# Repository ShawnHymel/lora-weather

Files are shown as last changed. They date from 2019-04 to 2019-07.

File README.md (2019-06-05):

LoRa Weather Station
====================

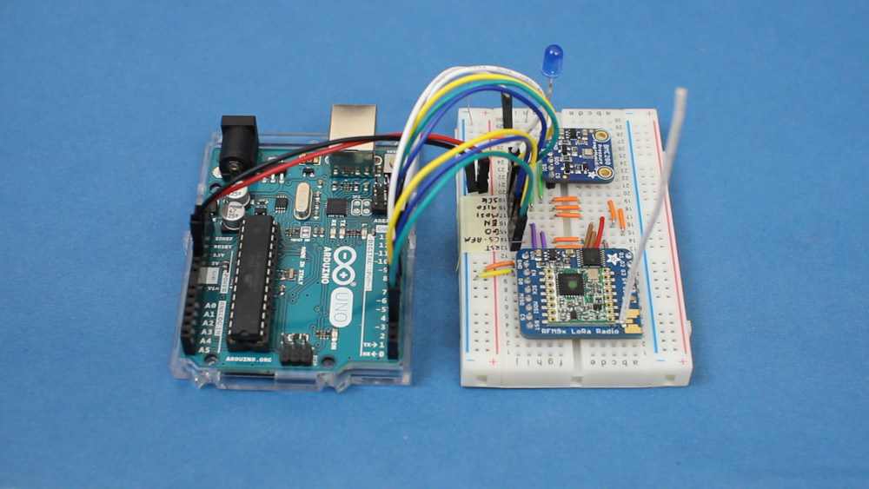
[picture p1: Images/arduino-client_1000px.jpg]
Arduino LoRa and BME280 client


LoRa client and server. Arduino reads temperature, humidity, and pressure data from BME280 sensor and sends it over a simple LoRa wireless connection to a Raspberry Pi.

Required Parts
--------------

 - [Arduino UNO](https://www.digikey.com/product-detail/en/A000066/1050-1024-ND/2784006/)
 - 2x [Adafruit RFM95W LoRa Breakout](https://www.digikey.com/product-detail/en/adafruit-industries-llc/3072/1528-1667-ND/6005357)
 - [Adafruit BME280 Breakout](https://www.digikey.com/product-detail/en/adafruit-industries-llc/2652/1528-1359-ND/5604372)
 - [Raspberry Pi 3 Model B+](https://www.digikey.com/product-detail/en/raspberry-pi/RASPBERRY-PI-3-MODEL-B/1690-1025-ND/8571724)
 - 2x [Breadboards](https://www.digikey.com/product-detail/en/bud-industries/BB-32621/377-2094-ND/4156445)
 - [Jumper wires](https://www.digikey.com/product-detail/en/global-specialties/WK-2/BKWK-2-ND/5231341)

Hardware Setup
--------------

Connect the Arduino as shown:

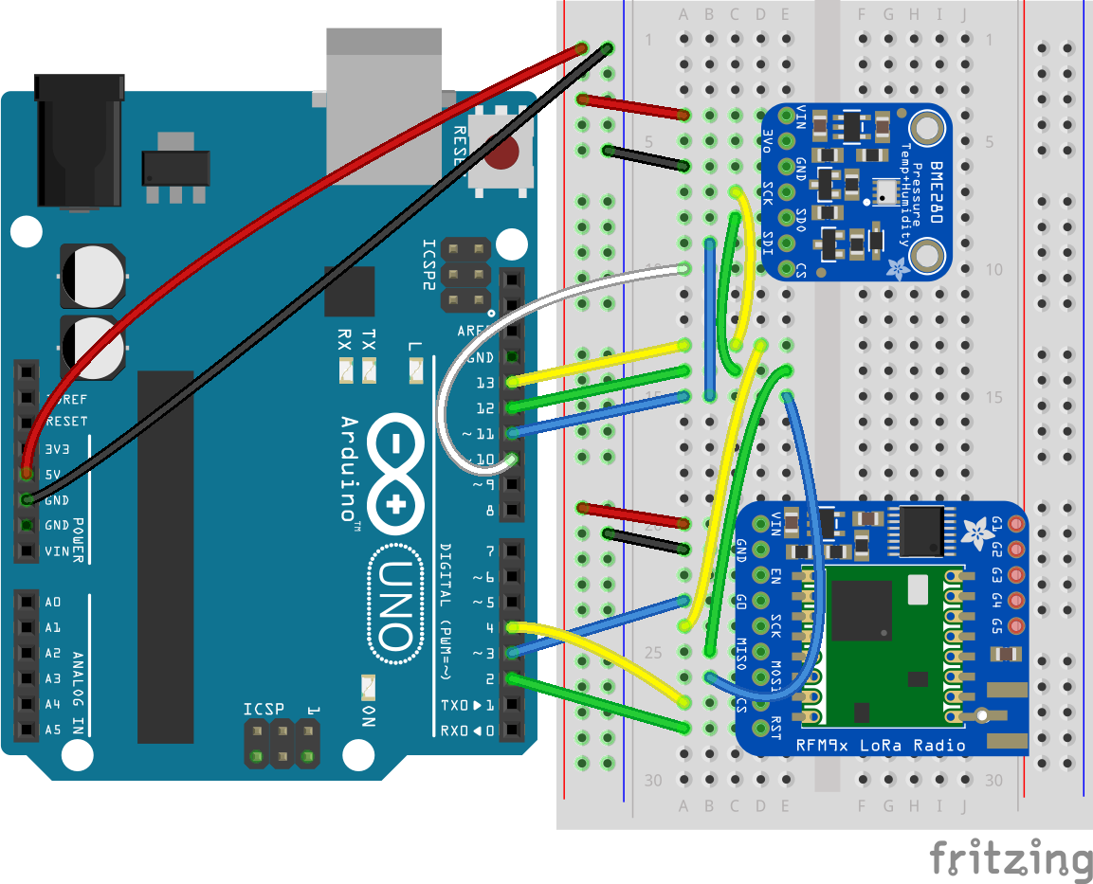
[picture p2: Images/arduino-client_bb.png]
Arduino radio and sensor connections


Connect the Raspberry Pi as shown:

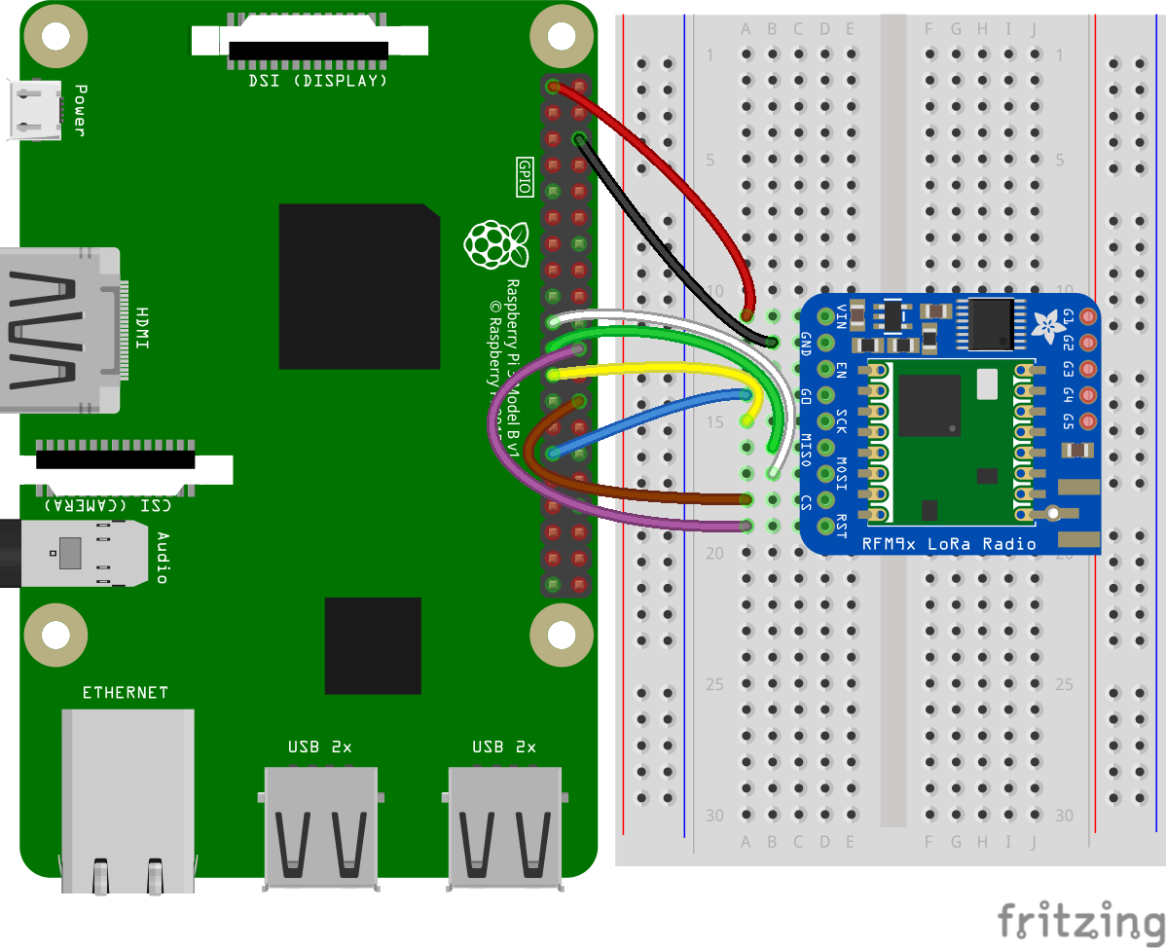
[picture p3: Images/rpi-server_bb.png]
Raspberry Pi radio connections


Server Software
---------------

Install Raspbian (with Desktop) on the Raspberry Pi. From a console, run the following command to install the RFM9x Python package:

```
pip install adafruit-circuitpython-rfm9x
```

Go into the *Python* directory of this repo and run *lora-weather-server.py*.

```
python lora-weather-server.py
```

Arduino Software
----------------

Install the following libraries for Arduino:
 - [RadioHead v1.59](http://www.airspayce.com/mikem/arduino/RadioHead/)
 - [Adafruit_Sensor](https://github.com/adafruit/Adafruit_Sensor)
 - [Adafruit_BME280_Library](https://github.com/adafruit/Adafruit_BME280_Library)
 
Upload the *lora-weather-client.ino* to the Arduino (found in the *Arduino* directory of this repository).

Running
-------

The Arduino should begin sending temperature, humidity, and pressure data to the Raspberry Pi at regular intervals. Check the console output to see the sensor data.

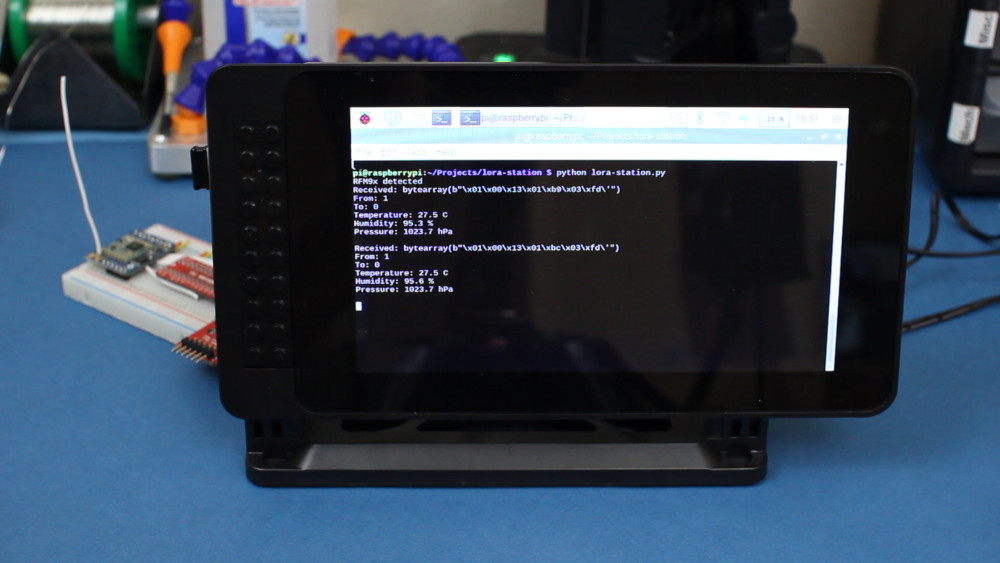
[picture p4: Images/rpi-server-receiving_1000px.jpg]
Sensor data printed to Raspberry Pi screen


License
-------

The code is beerware; if you see me at the local, and you've found the code helpful, please buy me a round!

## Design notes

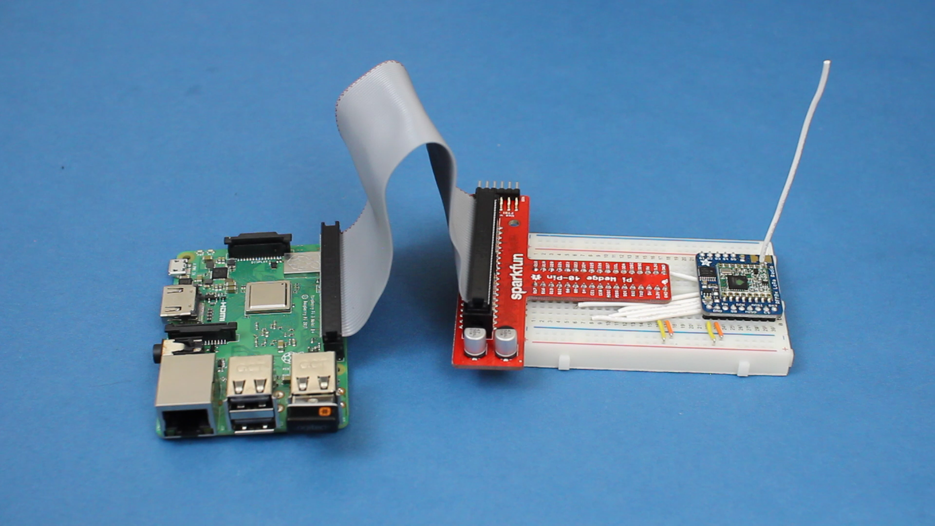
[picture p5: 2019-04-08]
Images/rpi-server.png

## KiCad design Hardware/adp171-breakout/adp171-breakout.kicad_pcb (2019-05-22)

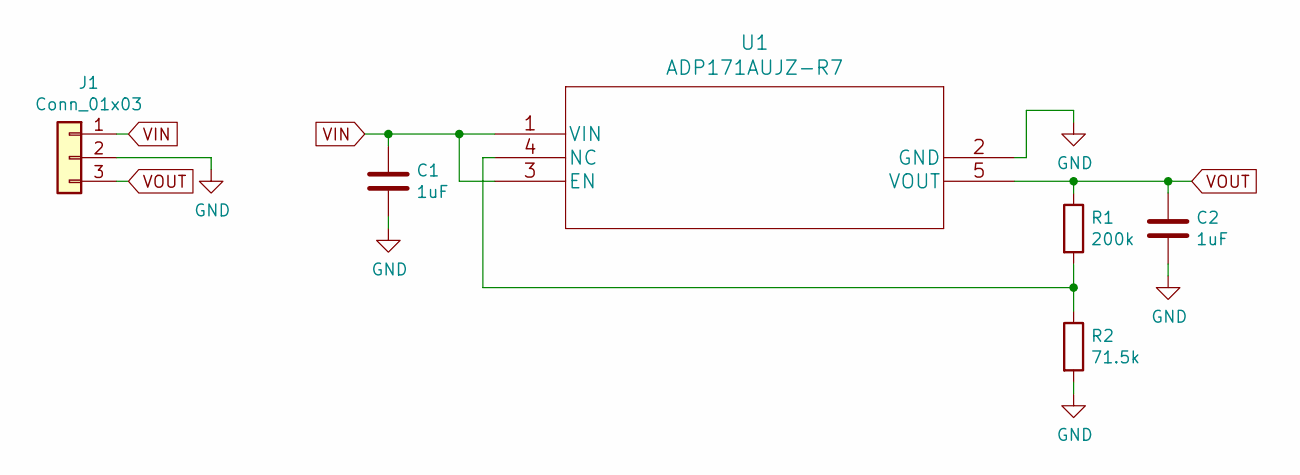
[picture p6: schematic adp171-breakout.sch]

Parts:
C1, C2: 1uF; C_0603_1608Metric
J1: Conn_01x03; PinHeader_1x03_P2.54mm_Vertical
R1: 200k; R_0603_1608Metric
R2: 71.5k; R_0603_1608Metric
U1: ADP171AUJZ-R7

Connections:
GND: C1.2, C2.2, J1.2, R2.2, U1.2 (GND)
unnamed: R1.2, R2.1, U1.4 (NC)
VIN: C1.1, J1.1, U1.1 (VIN), U1.3 (EN)
VOUT: C2.1, J1.3, R1.1, U1.5 (VOUT)

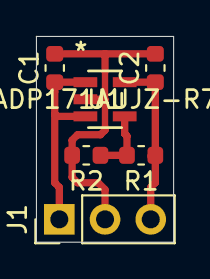
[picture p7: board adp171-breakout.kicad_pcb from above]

Board: 2 copper layers, 7.6 x 11.4 mm, 6 parts (0 on the bottom side), 4 nets.

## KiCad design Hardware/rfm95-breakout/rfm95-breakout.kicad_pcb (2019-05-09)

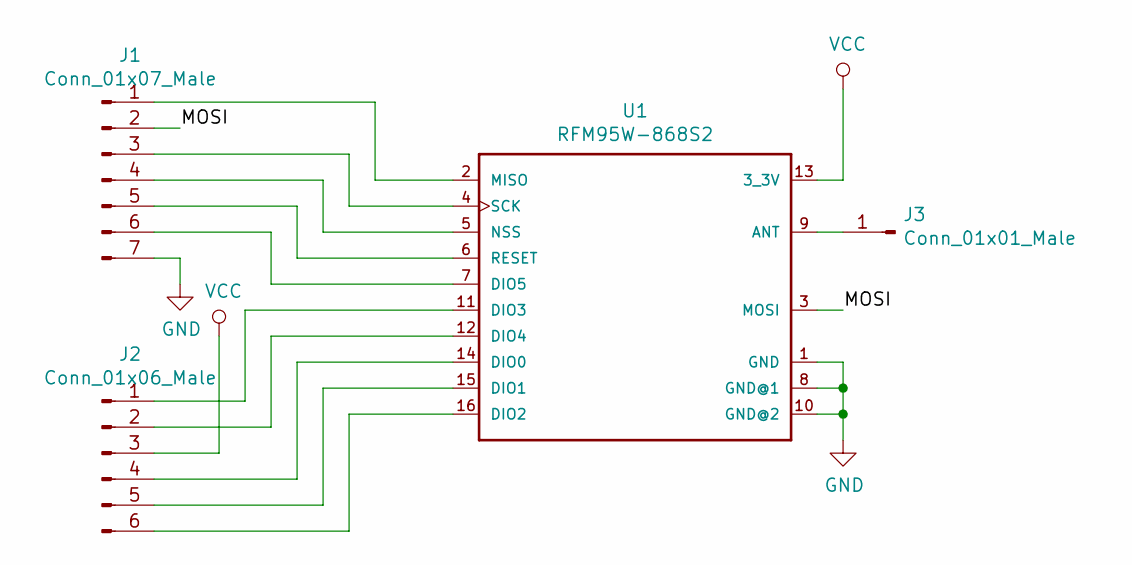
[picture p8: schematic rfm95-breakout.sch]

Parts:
J1: Conn_01x07_Male; PinHeader_1x07_P2.54mm_Vertical
J2: Conn_01x06_Male; PinHeader_1x06_P2.54mm_Vertical
J3: Conn_01x01_Male; PinHeader_1x01_P2.54mm_Vertical
U1: RFM95W-868S2; XCVR_RFM95W-868S2

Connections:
/MOSI: J1.2, U1.3 (MOSI)
GND: J1.7, U1.1 (GND), U1.8 (GND@1), U1.10 (GND@2)
unnamed: J1.1, U1.2 (MISO)
unnamed: J1.3, U1.4 (SCK)
unnamed: J1.4, U1.5 (NSS)
unnamed: J1.5, U1.6 (RESET)
unnamed: J1.6, U1.7 (DIO5)
unnamed: J2.1, U1.11 (DIO3)
unnamed: J2.2, U1.12 (DIO4)
unnamed: J2.4, U1.14 (DIO0)
unnamed: J2.5, U1.15 (DIO1)
unnamed: J2.6, U1.16 (DIO2)
unnamed: J3.1, U1.9 (ANT)
VCC: J2.3, U1.13 (3_3V)

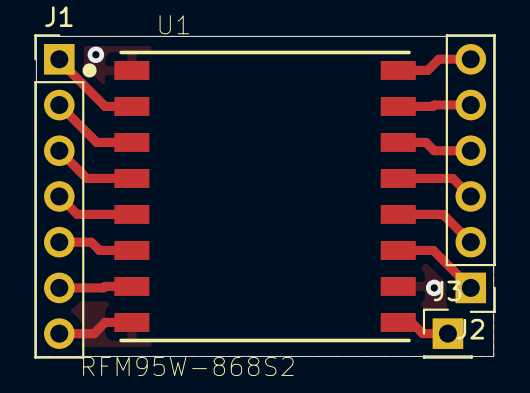
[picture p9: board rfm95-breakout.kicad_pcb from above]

Board: 2 copper layers, 25.4 x 17.8 mm, 4 parts (0 on the bottom side), 14 nets.

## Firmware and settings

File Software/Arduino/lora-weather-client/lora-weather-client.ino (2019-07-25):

 /**
 * LoRa Weather Client
 * 
 * Author: Shawn Hymel
 * Date: March 23, 2019
 * 
 * Transmits temperature, humidity, and pressure data over raw
 * LoRa radio. Reads data from BME280 sensor and transmits with
 * following packet:
 * 
 * | 1B From Addr | 1B To Addr | 2B Temp | 2B Humd | 2B Pres |
 *
 * Note that temperature, humidity, and pressure values are
 * scaled up by 10 and rounded to nearest integer before being
 * sent. The server will need to scale received values by 1/10.
 * This is to avoid sending full floating point values.
 * 
 * Required libraries:
 *  - http://www.airspayce.com/mikem/arduino/RadioHead/ (v1.59)
 *  - https://github.com/adafruit/Adafruit_Sensor
 *  - https://github.com/adafruit/Adafruit_BME280_Library
 * 
 * License: Beerware
 */

#include <Wire.h>
#include <SPI.h>

#include <Adafruit_Sensor.h>
#include <Adafruit_BME280.h>
#include <RH_RF95.h>

#define DEBUG 0

// Parameters
const uint8_t LORA_NODE_ADDR = 0x01;    // This node's address
const uint8_t LORA_SERVER_ADDR = 0x00;  // LoRa receiving address
const int WAIT_TIME = 30000;             // ms
const int TX_BUF_SIZE = 8;              // Transmit buffer size
const float RFM_FREQ = 915.0;           // Frequency for RFM95W
const int RFM_TX_POWER = 17;            // 5..23 dBm, 13 dBm is default
const uint16_t CUTOFF_ADC = 505;        // Cutoff voltage for device (1.9V)
const uint8_t WAKEUP_CYCLES = 7;        // 8 Sleep cycles

// Pins
// SPI:
// MOSI = 11
// MISO = 12
// SCK = 13
const int RFM_RST_PIN = 2;
const int RFM_INT_PIN = 3;
const int RFM_CS_PIN = 4;
const int BME_CS_PIN = 10;
const int V_EN_PIN = 8;
const int V_DIV_PIN = A0;

// Wakeup counter
uint8_t wakeup_count = WAKEUP_CYCLES;

// Instance of radio driver over SPI
RH_RF95 rfm(RFM_CS_PIN, RFM_INT_PIN);

// Communicate with BME280 over SPI
Adafruit_BME280 bme(BME_CS_PIN);

// Transmit buffer
uint8_t tx_buf[TX_BUF_SIZE];

void setup() {

#if DEBUG
  Serial.begin(9600);
#endif

  // Voltage divider enable
  pinMode(V_EN_PIN, OUTPUT);

  // Disable ADC (must be before writing to PRR or ADC will be stuck on)
  ADCSRA = 0;

  // Disable power to I2C, TIM2, TIM1, and ADC
  PRR = (1 << PRTWI) |    // TWI (I2C)
        (1 << PRTIM2) |   // Timer/Counter2
        (1 << PRTIM1) |   // Timer/Counter1
        (1 << PRADC);     // ADC*/

  // Initialize BME280
  if ( !bme.begin() ) {
#if DEBUG
    Serial.println("Could not find BME280 on SPI bus");
#endif
    while(1);
  }
#if DEBUG
    Serial.println("BME280 initialized");
#endif

  // Manually reset RFM95W
  pinMode(RFM_RST_PIN, OUTPUT);
  digitalWrite(RFM_RST_PIN, HIGH);
  delay(100);
  digitalWrite(RFM_RST_PIN, LOW);
  delay(10);
  digitalWrite(RFM_RST_PIN, HIGH);
  delay(10);

  // Initialize RFM95W
  if ( !rfm.init() ) {
#if DEBUG
    Serial.println("Could not initialize RFM95");
#endif
    while(1);
  }
#if DEBUG
  Serial.println("RFM95 initialized");
#endif

  // Set RFM95W frequency
  if ( !rfm.setFrequency(RFM_FREQ) ) {
#if DEBUG
    Serial.println("Could not set frequency on RFM95");
#endif
    while(1);
  }
#if DEBUG
  Serial.print("RFM95 frequency set to ");
  Serial.print(RFM_FREQ);
  Serial.println(" MHz");
#endif

  // Set RFM95W transmit power from PA_BOOST pin
  rfm.setTxPower(RFM_TX_POWER, false);



  // Set BME280 parameters for low power, forced mode
  bme.setSampling(bme.MODE_FORCED, 
                  bme.SAMPLING_X1,
                  bme.SAMPLING_X1,
                  bme.SAMPLING_X1,
                  bme.FILTER_OFF);
}

void loop() {

  // Check counter
  wakeup_count++;
  if ( wakeup_count > WAKEUP_CYCLES ) {
    wakeup_count = 0;
    
    // Turn power on to ADC
    PRR &= ~(1 << PRADC);
  
    // Enable ADC
    ADCSRA |= (1 << ADEN);
  
    // Discard first ADC reading
    analogRead(V_DIV_PIN);
  
    // Only take measurements and transmit if over cutoff voltage
    digitalWrite(V_EN_PIN, HIGH);
    uint16_t v_batt = analogRead(V_DIV_PIN);
    digitalWrite(V_EN_PIN, LOW);
  
    if ( v_batt > CUTOFF_ADC ) {
  
      // Perform forced measurement, then go back to sleep
      bme.takeForcedMeasurement();
      
      // Read data
      float temp = bme.readTemperature();
      float humd = bme.readHumidity();
      float pres = bme.readPressure() / 100.0;
      
      // Scale (x10) and round data
      int16_t tempt = (int16_t)((temp * 10.0) + 0.5);
      int16_t humdt = (int16_t)((humd * 10.0) + 0.5);
      int16_t prest = (int16_t)((pres * 10.0) + 0.5);
    
    #if DEBUG
      Serial.print("Temperature: ");
      Serial.print(temp, 1);
      Serial.println(" C");
      Serial.print("Humidity: ");
      Serial.print(humd, 1);
      Serial.println("%");
      Serial.print("Pressure: ");
      Serial.print(pres, 1);
      Serial.println(" hPa");
    #endif
      
      // Stuff buffer
      tx_buf[0] = LORA_NODE_ADDR;     // From address (this node) [1 byte]
      tx_buf[1] = LORA_SERVER_ADDR;   // To address (server) [1 byte]
      tx_buf[2] = (0xff & tempt);     // Temperature [2 bytes] little-endian
      tx_buf[3] = (0xff & (tempt >> 8));
      tx_buf[4] = (0xff & humdt);     // Humidity [2 bytes] little-endian
      tx_buf[5] = (0xff & (humdt >> 8));
      tx_buf[6] = (0xff & prest);     // Pressure [2 bytes] little-endian
      tx_buf[7] = (0xff & (prest >> 8));
    
    #if DEBUG
      Serial.print("Sending buffer:");
      for ( int i = 0; i < TX_BUF_SIZE; i++) {
        Serial.print(" 0x");
        Serial.print(tx_buf[i], HEX);
      }
      Serial.println();
      Serial.println();
    #endif
    
      // Send data to server
      rfm.send(tx_buf, TX_BUF_SIZE);
      rfm.waitPacketSent();
    }
  
    // Disable ADC (must be before writing to PRR or ADC will be stuck on)
    ADCSRA = 0;
  
    // Disable power to ADC
    PRR |= (1 << PRADC);
  
    // Put RFM95 to sleep
    rfm.sleep();
  }

  // Put 328p to sleep
  goToSleep();
}

// Interrupt Service Routine (Watchdog Timer)
ISR(WDT_vect) {

  // Disable Watchdog Timer
  asm("wdr");                         // Reset WDT
  WDTCSR |= (1 << WDCE) | (1 << WDE); // Special operation to change WDT config
  WDTCSR = 0x00;                      // Turn off WDT
}

// Set the processor to power-down sleep mode
void goToSleep() {

  // Disable interrupts while we configure sleep
  asm("cli");
  
  // Configure Watchdog Timer
  uint8_t wdt_timeout = (1 << WDP3) | (1 << WDP0); // 8.0 s timeout
  asm("wdr");                           // Reset WDT
  WDTCSR |= (1 << WDCE) | (1 << WDE);   // Special operation to change WDT config
  WDTCSR = (1 << WDIE) | wdt_timeout;   // Enable WDT interrupts, set timeout

  // Sleep sequence (call right before sleeping)
  SMCR |= (1 << SM1); // Power-down sleep mode
  SMCR |= (1 << SE);  // Enable sleep

  // Re-enable interrupts and call sleep instruction
  asm("sei");         // Enable interrupts     
  asm("sleep");       // Go to sleep

  // -> Wake up here <-

  // Disable sleeping as a precaution
  SMCR &= ~(1 << SE); // Disable sleep

  // Restore MCUCR
  //MCUCR = mcucr_backup;
}

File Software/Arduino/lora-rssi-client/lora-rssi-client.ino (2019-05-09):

/**
 * LoRa Echo Client
 * 
 * Author: Shawn Hymel
 * Date: May 8, 2019
 * 
 * Sends packet to station. Reply will be RSSI value seen at server.
 * 
 * Required libraries:
 *  - http://www.airspayce.com/mikem/arduino/RadioHead/ (v1.59)
 *  - https://github.com/sparkfun/SparkFun_Micro_OLED_Arduino_Library
 * 
 * License: Beerware
 */

// Uncomment if you want to use an OLED to display the RSSI
#define OLED

#include <SPI.h>
#include <Wire.h>
#include <RH_RF95.h>

#ifdef OLED
#include "SFE_MicroOLED.h"
#endif

// Parameters
const int TIMEOUT = 1000;               // Time (ms) to wait for a reply
const int WAIT_TIME = 200;              // Time (ms) between transmits
const int TX_BUF_SIZE = 8;              // Transmit buffer size (bytes)
const uint8_t RX_BUF_SIZE = 8;          // Receive buffer size (bytes)
const float RFM_FREQ = 915.0;           // Frequency for RFM95W
const int RFM_TX_POWER = 17;            // 5..23 dBm, 13 dBm is default
#ifdef OLED
const int OLED_DC_JUMPER = 1;           // Position of DC jumper
#endif

// Pins
// SPI:
// MOSI = 11
// MISO = 12
// SCK = 13
const int RFM_RST_PIN = 2;
const int RFM_INT_PIN = 3;
const int RFM_CS_PIN = 4;
const int BME_CS_PIN = 10;
const int LED_PIN = 7;
#ifdef OLED
const int OLED_RST = 9;
#endif

// Instance of radio driver over SPI
RH_RF95 rfm(RFM_CS_PIN, RFM_INT_PIN);

// Transmit buffer (constant)
const uint8_t tx_buf[] = {0x12, 0x34, 0x56, 0x78, 0x90, 0xab, 0xcd, 0xef};

// Receive buffer
uint8_t rx_buf[RX_BUF_SIZE];

// OLED object
#ifdef OLED
MicroOLED oled(OLED_RST, OLED_DC_JUMPER);
#endif

void setup() {

  // Set up Serial
  Serial.begin(9600);

  // Set up OLED
#ifdef OLED
  delay(100);
  Wire.begin();
  oled.begin();
  oled.clear(ALL);
  oled.setFontType(1);
#endif

  // Manually reset RFM95W
  pinMode(RFM_RST_PIN, OUTPUT);
  digitalWrite(RFM_RST_PIN, HIGH);
  delay(100);
  digitalWrite(RFM_RST_PIN, LOW);
  delay(10);
  digitalWrite(RFM_RST_PIN, HIGH);
  delay(10);

  // Initialize RFM95W
  if ( !rfm.init() ) {
    Serial.println("Could not initialize RFM95");
    while(1);
  }
  Serial.println("RFM95 initialized");

  // Set RFM95W frequency
  if ( !rfm.setFrequency(RFM_FREQ) ) {
    Serial.println("Could not set frequency on RFM95");
    while(1);
  }
  Serial.print("RFM95 frequency set to ");
  Serial.print(RFM_FREQ);
  Serial.println(" MHz");

}

void loop() {

#ifdef OLED
  int mid_x = oled.getLCDWidth() / 2;
  int mid_y = oled.getLCDHeight() / 2;
#endif

  // Send data to server
  rfm.send(tx_buf, TX_BUF_SIZE);
  rfm.waitPacketSent();

  // Wait for a reply from server
  if (rfm.waitAvailableTimeout(TIMEOUT)) { 
    uint8_t rx_buf_size = RX_BUF_SIZE;  // Dunno why they want a pointer...
    if (rfm.recv(rx_buf, &rx_buf_size)) {
      Serial.print("Server RSSI:\t-");
      Serial.println(rx_buf[0]);
#ifdef OLED
      oled.clear(PAGE);
      if ( rx_buf[0] < 255 ) {
        oled.setCursor(mid_x - 12, mid_y - 8);
        oled.print(-1 * rx_buf[0]);
      } else {
        oled.setCursor(mid_x - 2, mid_y - 8);
        oled.print("ERROR");
      }
      oled.display();
#endif
    } else {
      Serial.println("Receive failed");
#ifdef OLED
      oled.clear(PAGE);
      oled.setCursor(0, mid_y - 8);
      oled.print("Rx Fail");
      oled.display();
#endif
    }
  } else {
    Serial.println("No reply, is the echo server running?");
#ifdef OLED
    oled.clear(PAGE);
    oled.setCursor(0, mid_y - 8);
    oled.print("NoReply");
    oled.display();
#endif
  }

  delay(WAIT_TIME);
}

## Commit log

2019-03-29 Added Arduino files and README
2019-04-08 Added images
    [arduino-client.fzz, rpi-server.fzz]
2019-05-09 Added rssi client test
    [rfm95-breakout.kicad_pcb, rfm95-breakout.sch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]
2019-05-22 Added ADP171 breakout
    [adp171-breakout.kicad_pcb, adp171-breakout.sch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]
2019-07-25 Added INA212 breakout and code for ep 9
    [ina21x-breakout.kicad_pcb, ina21x-breakout.sch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]

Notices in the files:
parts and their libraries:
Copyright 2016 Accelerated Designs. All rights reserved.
